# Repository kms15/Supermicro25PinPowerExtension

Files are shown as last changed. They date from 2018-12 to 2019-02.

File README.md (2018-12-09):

# Supermicro 25 Pin Power Extension

This project is an extension cable for a Super Micro PWS-1K66P-1R power supply.
This power supply has a 40mm fan which is quite loud, but the design of many
servers does not leave enough space around the power supply to replace this fan
with a larger (and quieter) fan.  The connector on this power supply is a
proprietary 2x25 contact PCB edge connector that carries high (133 Amp)
currents, and thus needs a custom extension cable to move the power supply out
of the case to somewhere with more space.

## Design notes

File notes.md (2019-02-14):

# Notes

## Datasheet links:
  - [Supermicro power supply dimensions](
    https://store.supermicro.com/media/wysiwyg/productspecs/PWS-1K66P-1R/PWS-1k66P-1R_quick_spec.pdf)
  - [Compatible? PCB edge connector: Amphenol 10035388-102LF](
    https://www.mouser.com/datasheet/2/18/10035388-1360968.pdf)
  - [4 pin disk drive power connector (TE 641737-1)](
    https://www.mouser.com/datasheet/2/418/NG_CS_82181_SOFTSHELL_STANDARD_DENSITY_0508-1262029.pdf)
  - [4 pin fan connector (Molex 47054-1000)](
    https://www.mouser.com/datasheet/2/276/0470531000_PCB_HEADERS-146351.pdf)
  - [PWM fan specification](
    http://handsontec.com/pdf_files/4_Wire_PWM_Spec.pdf)

## connector layout
Looking from front of case, 7+7 signal pins (top + bottom), then 9+9 pins
of +12V (top + bottom), and finally 9+9 pins of ground (top + bottom)

## Fan connector:
There is what appears to be an 8 pin JST connector on a vertically mounted
daughter board near the left edge of the card edge connector with a cable
that connects to the twin fans. Disconnecting the cable causes the power
supply to error on startup. Probing it with a multimeter shows the
following: (numbering from the left/bottom pin of the fan connector on the pcb)

1. ~200 Hz square wave (tachometer? 2 counts per cycle?)
2. ~150 Hz square wave (tachometer? 2 counts per cycle?)
3. +3 Vpp square wave ~30% duty cycle 50 kHz (PWM control?)
4. +3 Vpp square wave ~30% duty cycle 50 kHz (PWM control?)
5. 0V (ground?)
6. 0V (ground?)
7. +11.75V (power vs. power sense?)
8. +12V (power?)

Hypothesis: this is likely to be a variation of the standard 4 pin fan
connector, in which case it should be possible to simulate a fan by connecting
two NPN transistors with the collectors connected to pins 1 and 2, the emitters
connected to ground/pins 5 and 6, and the gate connected to a ~200 Hz square
wave. I would still need to provide sufficient airflow to keep the power supply
cool at full load, of course (or, if that proves to be too noisy, use the PWM
outputs from pin 3 & 4 to be able to ramp up the fan speed when needed).

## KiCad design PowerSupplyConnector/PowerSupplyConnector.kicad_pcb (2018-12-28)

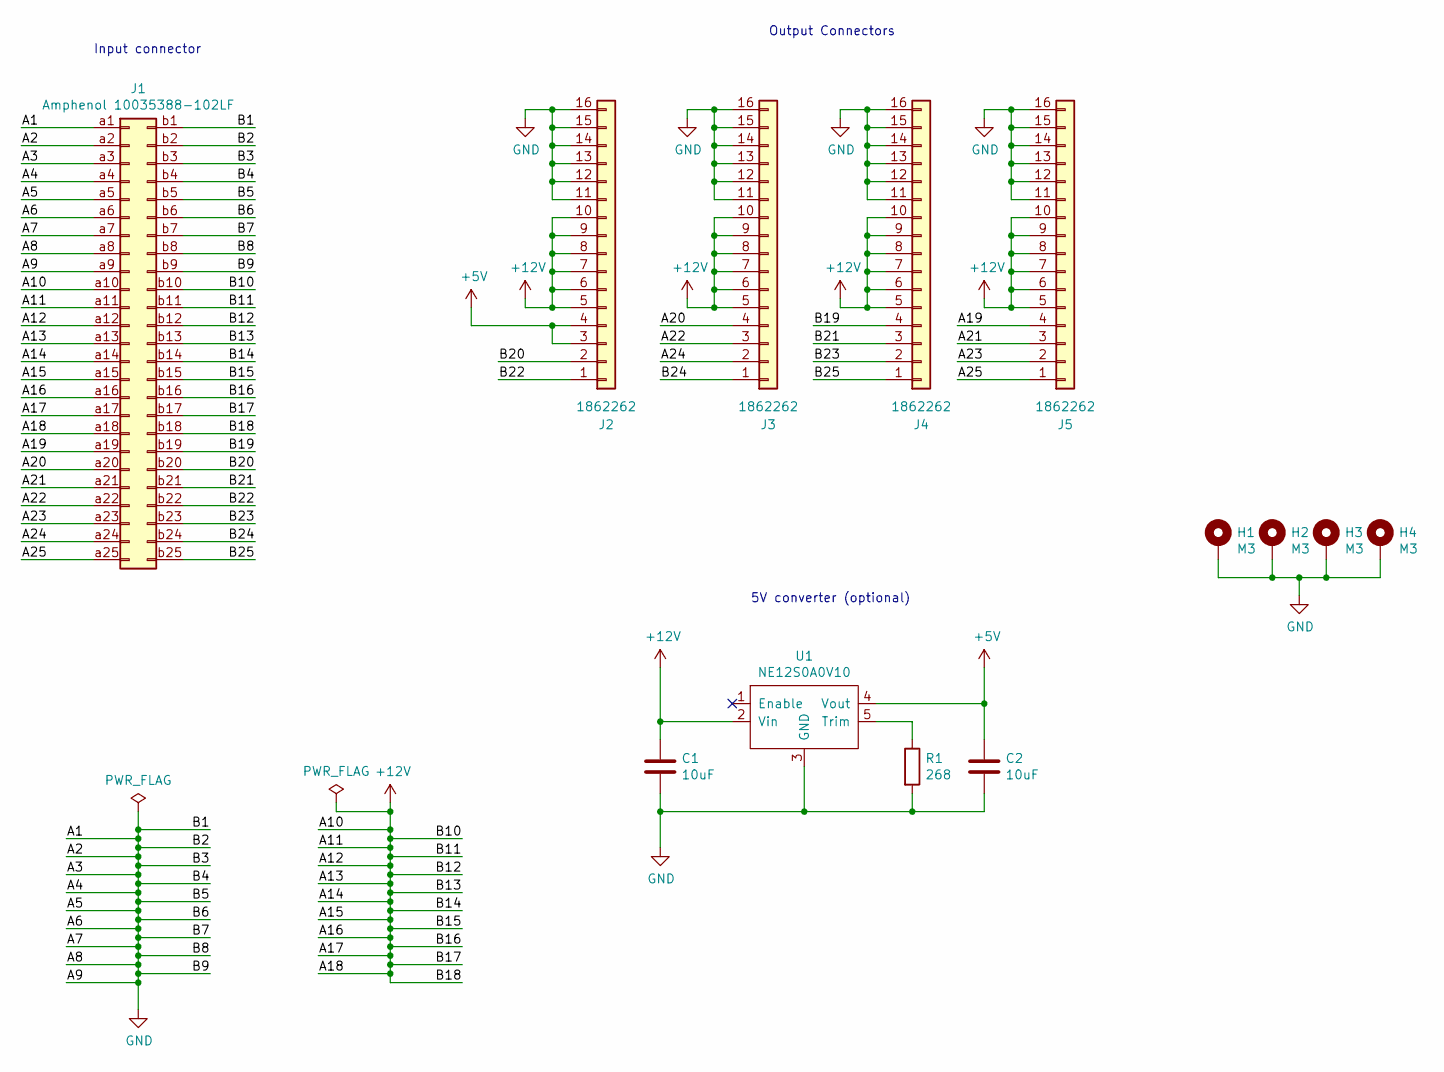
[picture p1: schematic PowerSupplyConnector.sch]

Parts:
C1, C2: 10uF; C_0603_1608Metric
H1, H2, H3, H4: M3; MountingHole_3.2mm_M3_Pad
J1: Amphenol 10035388-102LF; Amphenol_10035388-102LF
J2, J3, J4, J5: 1862262; PhoenixContact1862262
R1: 268; R_0603_1608Metric
U1: NE12S0A0V10; Delta_NE12S0A0V10

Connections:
+5V: C2.1, J2.3, J2.4, U1.4 (Vout)
+12V: C1.1, J1.a10, J1.a11, J1.a12, J1.a13, J1.a14, J1.a15, J1.a16, J1.a17, J1.a18, J1.b10, J1.b11, J1.b12, J1.b13, J1.b14, J1.b15, J1.b16, J1.b17, J1.b18, J2.5, J2.6, J2.7, J2.8, J2.9, J2.10, J3.5, J3.6, J3.7, J3.8, J3.9, J3.10, J4.5, J4.6, J4.7, J4.8, J4.9, J4.10, J5.5, J5.6, J5.7, J5.8, J5.9, J5.10, U1.2 (Vin)
/A19: J1.a19, J5.4
/A20: J1.a20, J3.4
/A21: J1.a21, J5.3
/A22: J1.a22, J3.3
/A23: J1.a23, J5.2
/A24: J1.a24, J3.2
/A25: J1.a25, J5.1
/B19: J1.b19, J4.4
/B20: J1.b20, J2.2
/B21: J1.b21, J4.3
/B22: J1.b22, J2.1
/B23: J1.b23, J4.2
/B24: J1.b24, J3.1
/B25: J1.b25, J4.1
GND: C1.2, C2.2, H1.1, H2.1, H3.1, H4.1, J1.a1, J1.a2, J1.a3, J1.a4, J1.a5, J1.a6, J1.a7, J1.a8, J1.a9, J1.b1, J1.b2, J1.b3, J1.b4, J1.b5, J1.b6, J1.b7, J1.b8, J1.b9, J2.11, J2.12, J2.13, J2.14, J2.15, J2.16, J3.11, J3.12, J3.13, J3.14, J3.15, J3.16, J4.11, J4.12, J4.13, J4.14, J4.15, J4.16, J5.11, J5.12, J5.13, J5.14, J5.15, J5.16, R1.2, U1.3 (GND)
unnamed: R1.1, U1.5 (Trim)

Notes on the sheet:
Input connector
Output Connectors
5V converter (optional)

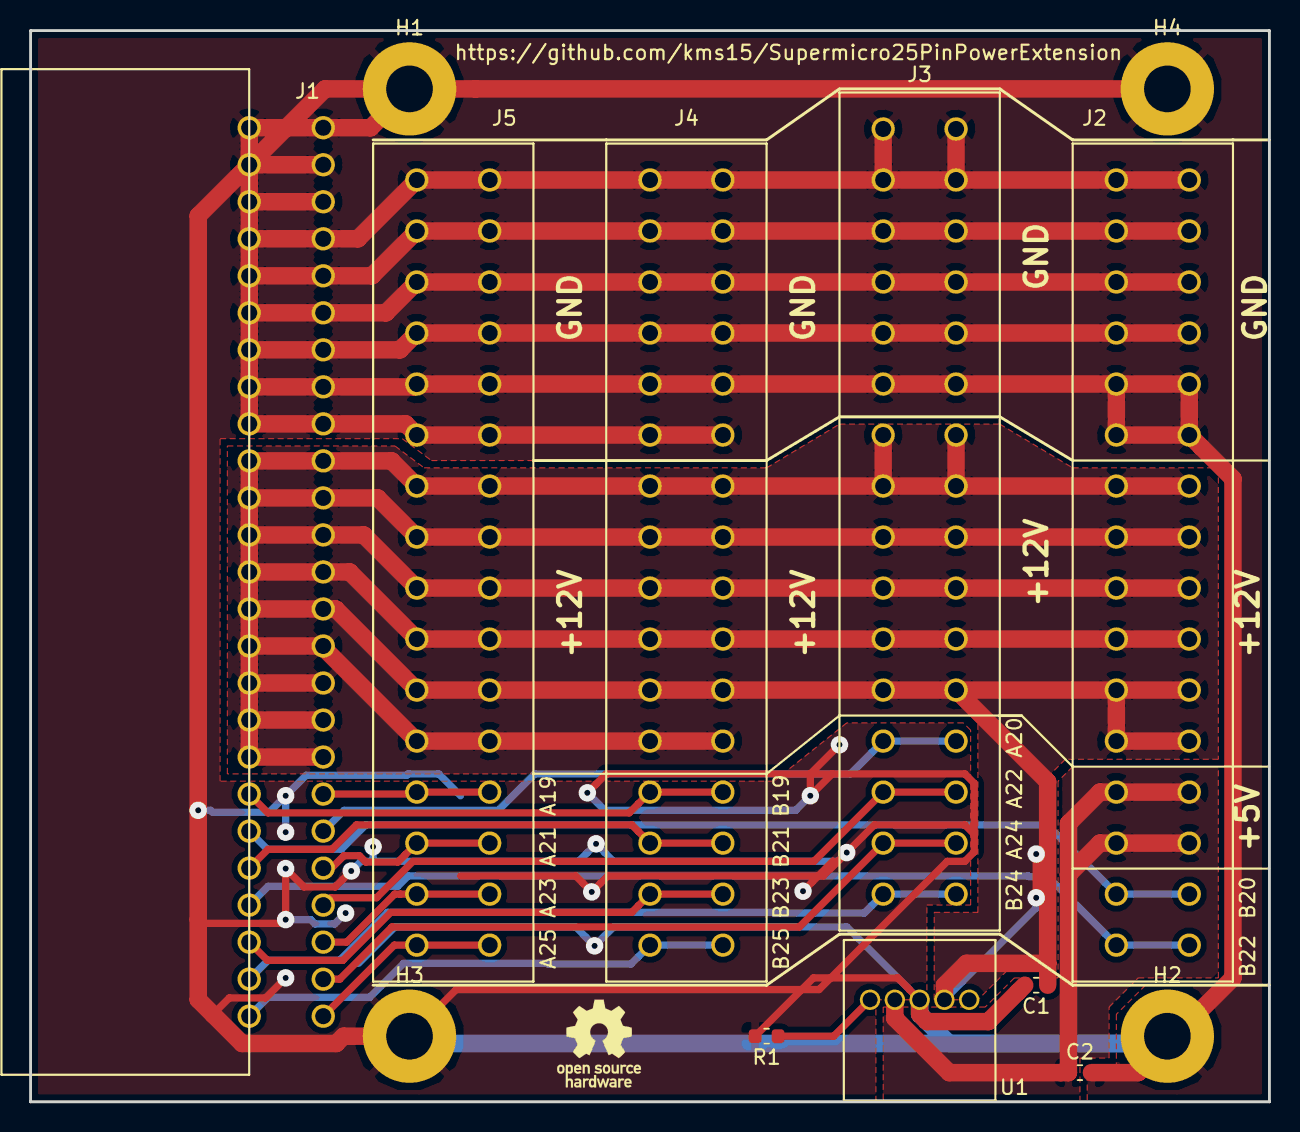
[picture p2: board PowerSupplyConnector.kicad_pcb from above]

Board: 2 copper layers, 85.0 x 73.5 mm, 13 parts (0 on the bottom side), 18 nets.

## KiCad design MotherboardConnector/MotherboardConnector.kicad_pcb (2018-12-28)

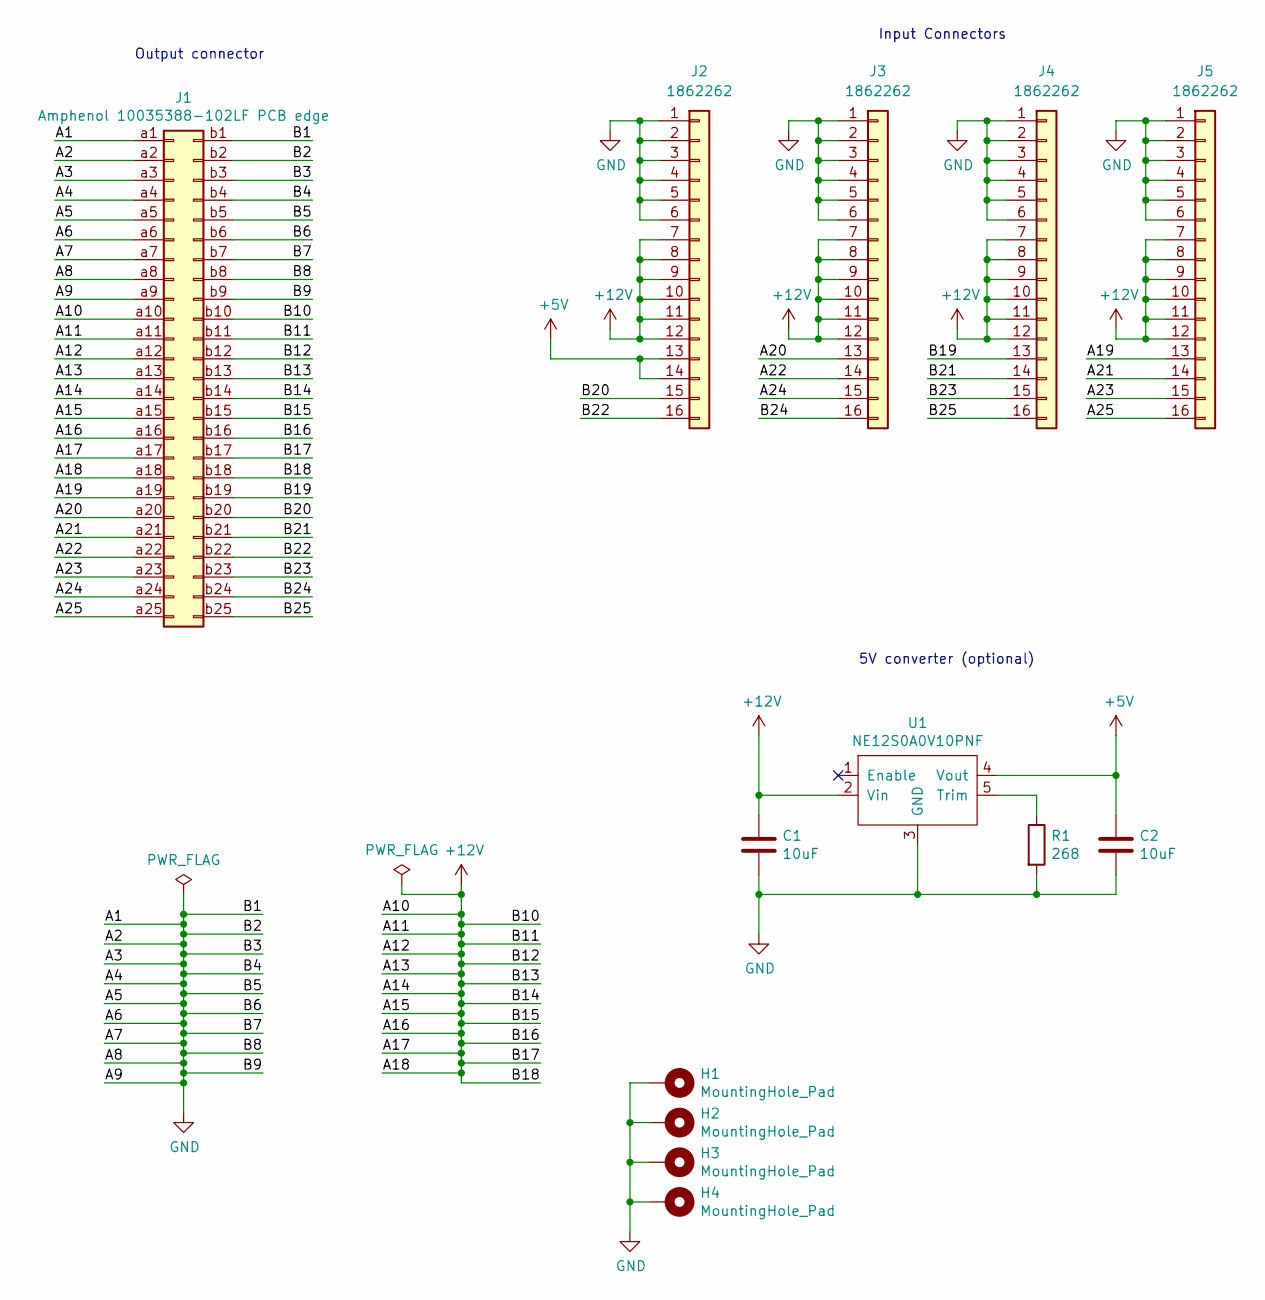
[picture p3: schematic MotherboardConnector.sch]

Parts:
C1, C2: 10uF; C_0603_1608Metric
H1, H2, H3, H4: MountingHole_Pad; MountingHole_3.2mm_M3_Pad
J1: Amphenol 10035388-102LF PCB edge; Amphenol_10035388-102LF_PCB_Edge
J2, J3, J4, J5: 1862262; PhoenixContact1862262
R1: 268; R_0603_1608Metric
U1: NE12S0A0V10PNF; Delta_NE12S0A0V10

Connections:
+5V: C2.1, J2.13, J2.14, U1.4 (Vout)
+12V: C1.1, J1.a10, J1.a11, J1.a12, J1.a13, J1.a14, J1.a15, J1.a16, J1.a17, J1.a18, J1.b10, J1.b11, J1.b12, J1.b13, J1.b14, J1.b15, J1.b16, J1.b17, J1.b18, J2.7, J2.8, J2.9, J2.10, J2.11, J2.12, J3.7, J3.8, J3.9, J3.10, J3.11, J3.12, J4.7, J4.8, J4.9, J4.10, J4.11, J4.12, J5.7, J5.8, J5.9, J5.10, J5.11, J5.12, U1.2 (Vin)
/A19: J1.a19, J5.13
/A20: J1.a20, J3.13
/A21: J1.a21, J5.14
/A22: J1.a22, J3.14
/A23: J1.a23, J5.15
/A24: J1.a24, J3.15
/A25: J1.a25, J5.16
/B19: J1.b19, J4.13
/B20: J1.b20, J2.15
/B21: J1.b21, J4.14
/B22: J1.b22, J2.16
/B23: J1.b23, J4.15
/B24: J1.b24, J3.16
/B25: J1.b25, J4.16
GND: C1.2, C2.2, H1.1, H2.1, H3.1, H4.1, J1.a1, J1.a2, J1.a3, J1.a4, J1.a5, J1.a6, J1.a7, J1.a8, J1.a9, J1.b1, J1.b2, J1.b3, J1.b4, J1.b5, J1.b6, J1.b7, J1.b8, J1.b9, J2.1, J2.2, J2.3, J2.4, J2.5, J2.6, J3.1, J3.2, J3.3, J3.4, J3.5, J3.6, J4.1, J4.2, J4.3, J4.4, J4.5, J4.6, J5.1, J5.2, J5.3, J5.4, J5.5, J5.6, R1.2, U1.3 (GND)
unnamed: R1.1, U1.5 (Trim)

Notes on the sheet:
Output connector
Input Connectors
5V converter (optional)

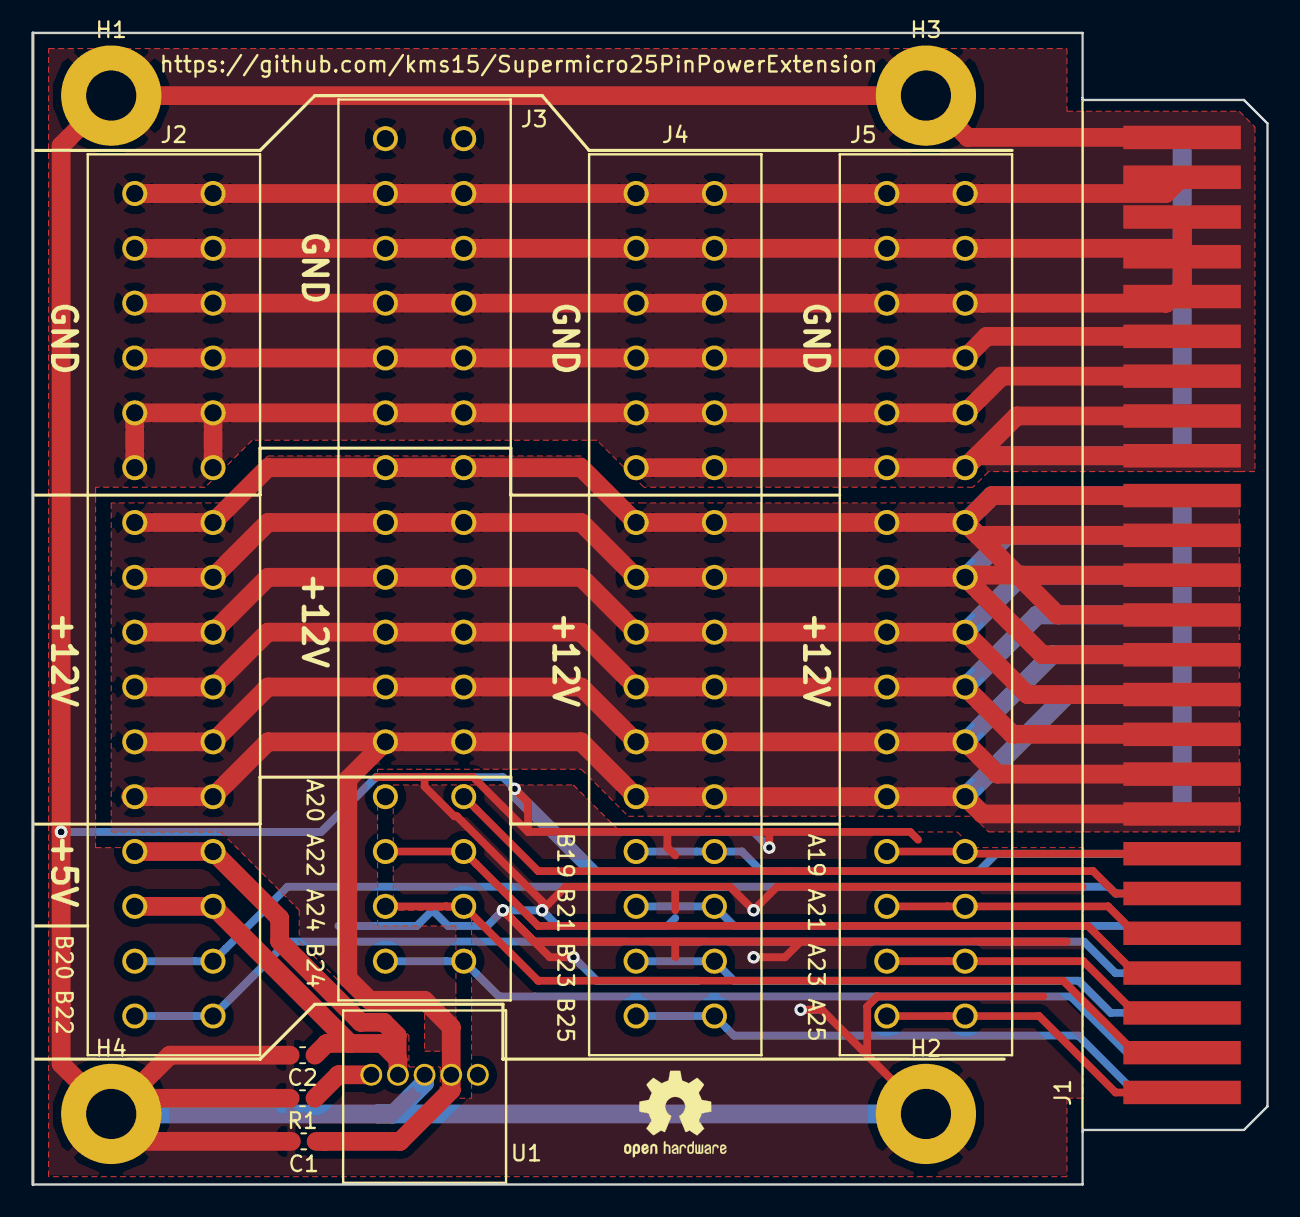
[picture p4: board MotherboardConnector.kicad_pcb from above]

Board: 2 copper layers, 78.8 x 73.5 mm, 13 parts (0 on the bottom side), 18 nets.

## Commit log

2018-12-09 add initial kicad schematics
    [MotherboardConnector.kicad_pcb, MotherboardConnector.sch, PowerSupplyConnector.kicad_pcb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]
2018-12-10 added PCB edge connector
2018-12-10 add remaining footprints
2018-12-13 remove soldermask from edge connector
2018-12-13 change to terminal block connector
    [MotherboardConnector.sch, PowerSupplyConnector.sch]
2018-12-13 fix symbol path issue
    [MotherboardConnector.sch]
2018-12-17 first draft of pcb for power supply side
    [PowerSupplyConnector.kicad_pcb, PowerSupplyConnector.sch]
2018-12-25 Motherboard connector PCB traces completed
    [MotherboardConnector.kicad_pcb, MotherboardConnector.sch]
2018-12-26 completed motherboard connector PCB
    [MotherboardConnector.kicad_pcb]
2018-12-28 add Panelized PCB layout
2019-02-14 add notes on fan connector in power supply
